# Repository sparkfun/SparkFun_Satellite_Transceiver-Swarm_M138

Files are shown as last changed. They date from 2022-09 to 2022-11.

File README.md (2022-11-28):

SparkFun Satellite Transceiver - Swarm M138
========================================

SparkFun Satellite Transceiver Kit - Swarm M138

[*SparkFun Satellite Transceiver Kit - Swarm M138 (21287)*](https://www.sparkfun.com/products/21287)

Looking for a low-cost way to send and receive data messages via satellite? This is it! With a clear view of the sky, the Satellite Transceiver Kit - Swarm M138 allows you to send and receive short messages. It works anywhere in the world, including the polar regions, far beyond the reach of WiFi and Cellular networks. It is perfect for a variety of low-bandwidth use cases: from connecting people and tracking vehicles, ships, or packages to relaying sensor data for agriculture, energy, and industrial IoT applications. The built-in GNSS receiver makes it perfect for many tracking applications.

At the heart of our product is a Swarm M138 satellite modem. This is a Mini-PCI Express Card containing both the satellite modem and a very capable GNSS receiver, all in one integrated package! It can operate from a wide range of supply voltages: 3.0V Min; 5.0V Max. Its standard 3.3V CMOS serial UART interface and NMEA-style command set makes it easy to integrate into your project. Our board includes both a USB-C interface (for power and/or serial data) and a full set of breakout pins. Want to plug it into your laptop or Raspberry Pi and use it to communicate out in the field? You can absolutely do that! We've written a Python3 PyQt5 GUI to get you started. Full details are available in the [hookup guide](https://learn.sparkfun.com/tutorials/sparkfun-satellite-transceiver-kit---swarm-m138-hookup-guide) and in the [product repo](https://github.com/sparkfun/SparkFun_Satellite_Transceiver-Swarm_M138). Want to connect it to your Arduino microcontroller board? You can absolutely do that too! Our [Swarm Arduino Library](https://github.com/sparkfun/SparkFun_Swarm_Satellite_Arduino_Library) makes that easy.

Our kit contains everything you need to get started:

* Swarm M138 Modem
* SparkFun Satellite Transceiver Breakout
* VHF Antenna and Ground Plane
* GNSS Antenna
* u.FL cables, adapter and screws

Repository Contents
-------------------

* **/Documentation** - Data sheets, additional product information
* **/Hardware** - Eagle design files (.brd, .sch)
* **/Production** - Production panel files (.brd)
* **/Tools/Swarm_M138_GUI** - Executables, Python files

Documentation
--------------
* **[Library](https://github.com/sparkfun/SparkFun_Swarm_Satellite_Arduino_Library)** - Arduino library for the SparkFun Satellite Transceiver Kit - Swarm M138.
* **[Hookup Guide](https://learn.sparkfun.com/tutorials/sparkfun-satellite-transceiver-kit---swarm-m138-hookup-guide)** - Basic hookup guide for the SparkFun Satellite Transceiver Kit - Swarm M138.

Product Versions
----------------
* [SPX-19236](https://www.sparkfun.com/products/19236)- SparkX version of this kit

License Information
-------------------

This product is _**open source**_! 

Please review the LICENSE.md file for license information. 

If you have any questions or concerns on licensing, please contact technical support on our [SparkFun forums](https://forum.sparkfun.com/viewforum.php?f=152).

Distributed as-is; no warranty is given.

- Your friends at SparkFun.

_<COLLABORATION CREDIT>_

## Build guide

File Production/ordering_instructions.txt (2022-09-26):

panel size, 158x103mm
PCB thickness, 1.6mm
number of layers, 2
soldermask color, Red
silkscreen color, White
oz copper, 1oz
finish, HASL lead free
stencils, top
pcs per panel, 4
min trace width, 0.1524mm / 0.0060in
min drill size, 0.3000mm / 0.0118in

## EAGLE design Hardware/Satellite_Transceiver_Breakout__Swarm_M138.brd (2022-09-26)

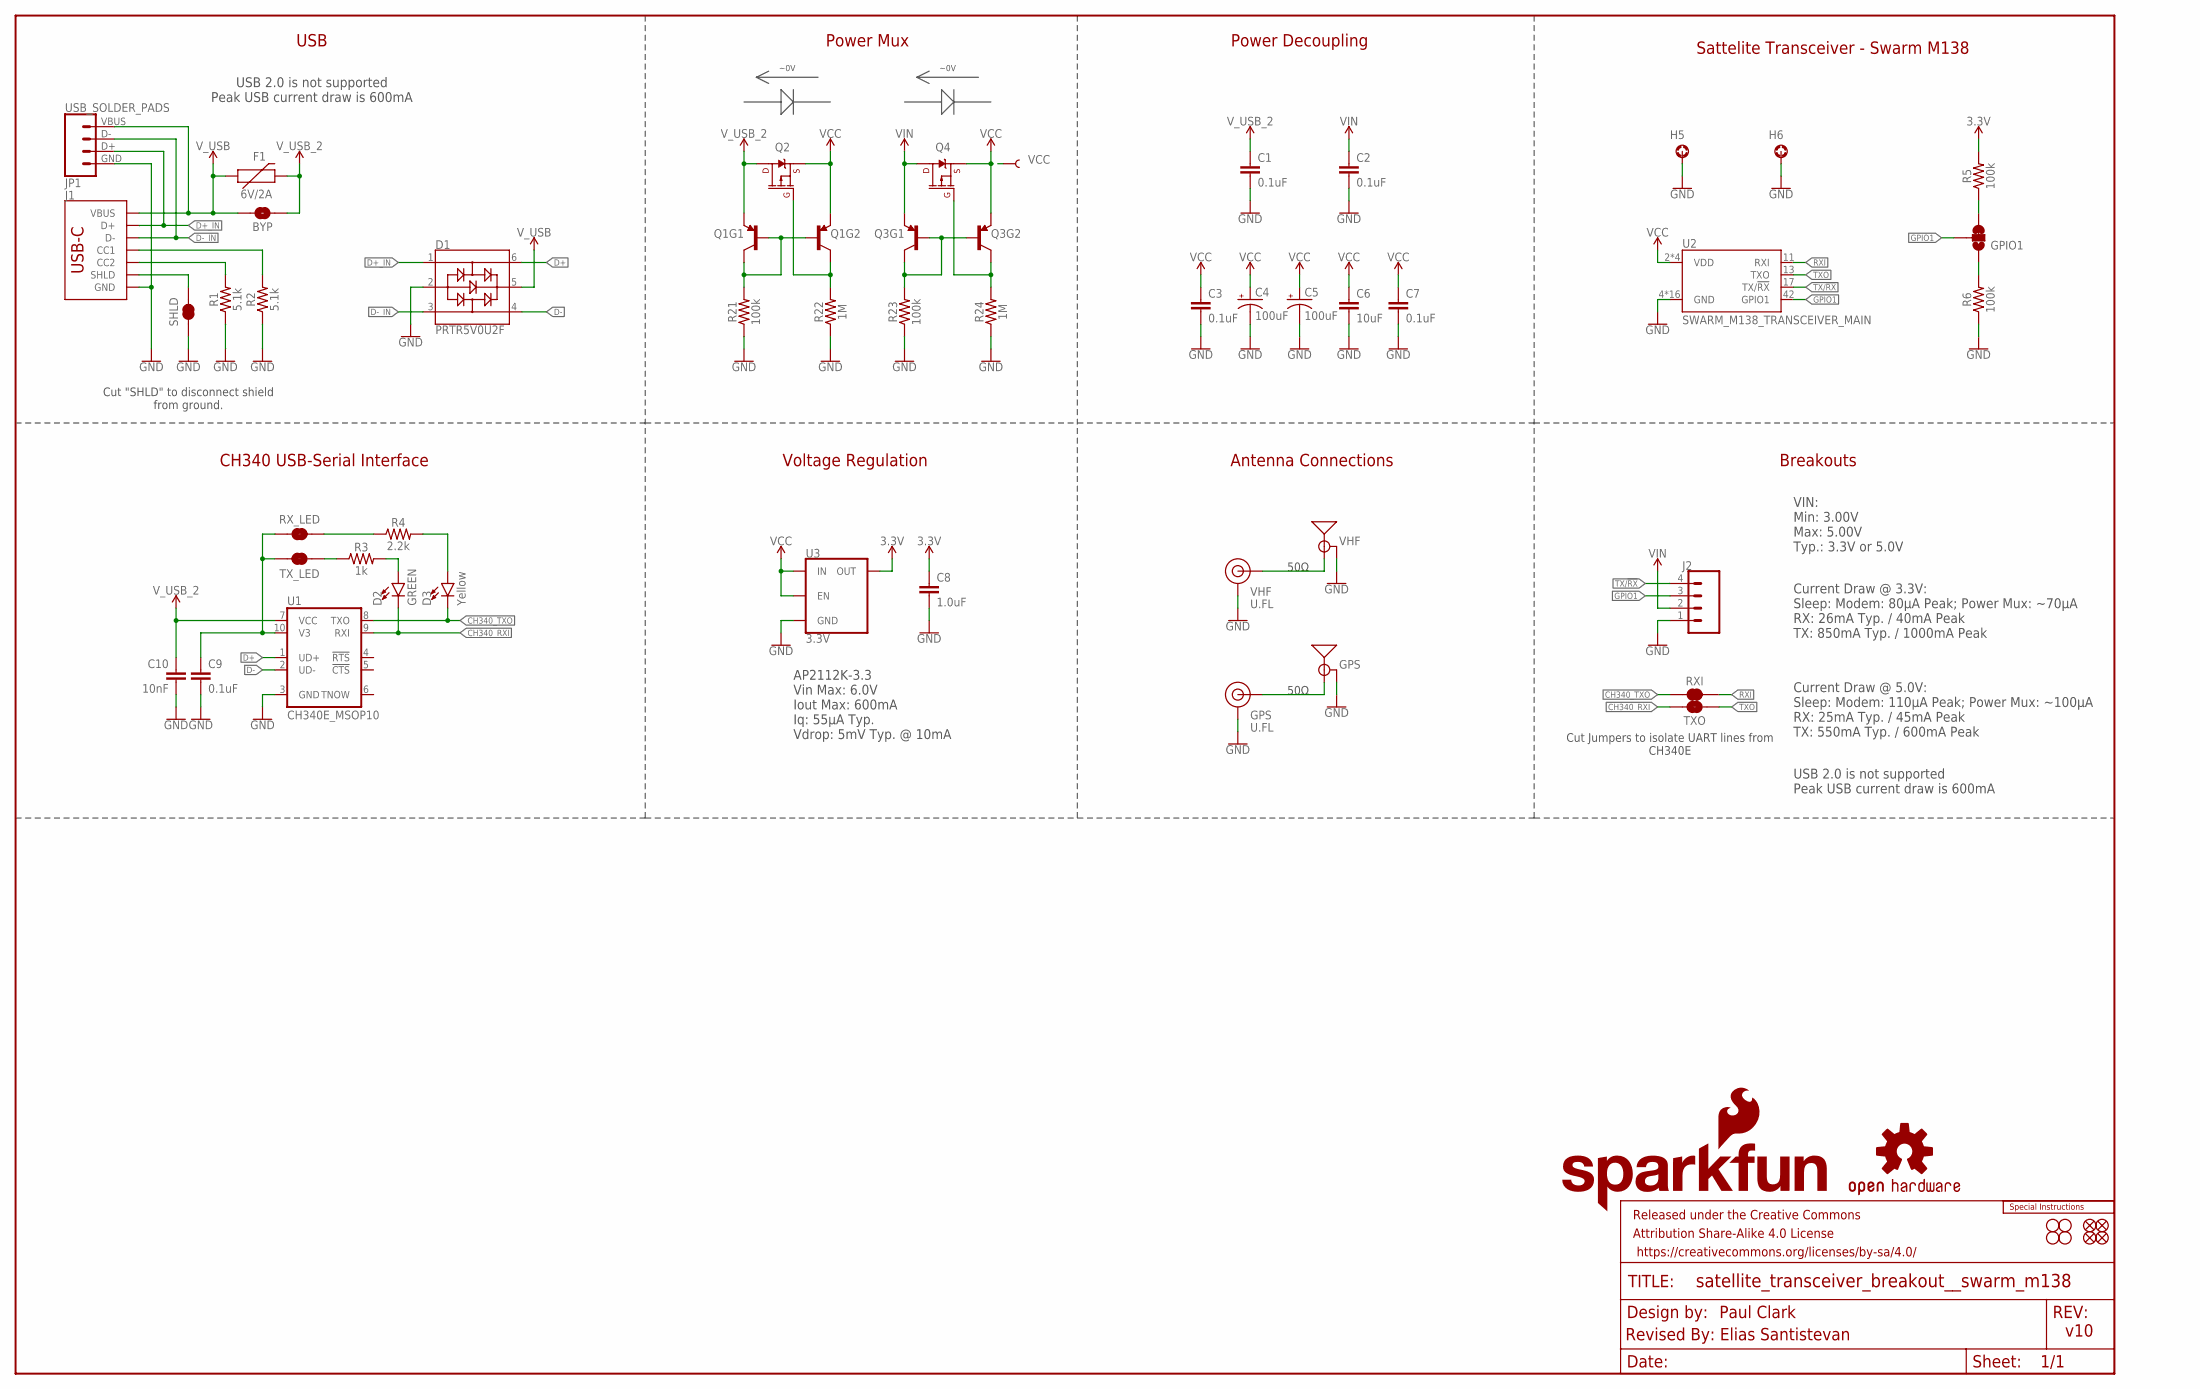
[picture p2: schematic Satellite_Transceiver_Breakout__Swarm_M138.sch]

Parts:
BYP: JUMPER-SMT_2_NO_SILK; SMT-JUMPER_2_NO_SILK
C1, C2, C3, C7, C9: 0.1uF; 0603
C4, C5: 100uF; PANASONIC_D
C6: 10uF; 0603
C8: 1.0uF; 0603
C10: 10nF; 0603
D1: PRTR5V0U2F; SOT886
D2: GREEN; LED-0603
D3: Yellow; LED-0603
E1: VHF; SMA-EDGE
E2: GPS; SMA-EDGE
F1: 6V/2A; 1210
FD1, FD2, FD3, FD4: FIDUCIAL1X2; FIDUCIAL-1X2
FRAME1: FRAME-LEDGER; CREATIVE_COMMONS
GPIO1: JUMPER-SMT_3_1-NC_TRACE_SILK; SMT-JUMPER_3_1-NC_TRACE_SILK
GPS: U.FL
H1, H2, H3, H4: STAND-OFF
H5, H6: STAND-OFF-REFLOW-M2.5_1.5MM_TALL; STAND-OFF-REFLOW-M2.5
J1: USB_C_2-LAYER_PADS; USB-C-16P-2LAYER-PADS
J2: CONN_041X04_NO_SILK; 1X04_NO_SILK
JP1: USB_SOLDER_PADS; USB-SOLDER-PADS
LOGO1: SPECIAL_INSTRUCTIONS-ORDERING; ORDERING_INSTRUCTIONS
LOGO2: OSHW-LOGOM; OSHW-LOGO-M
LOGO4: SFE_LOGO_NAME_FLAME.1_INCH; SFE_LOGO_NAME_FLAME_.1
Q1, Q3: TRANS_PNP_DUALSOT-363; SOT363_PHILIPS
Q2, Q4: 20V/4.2A/52mΩ/1.4W; SOT23-3
R1, R2: 5.1k; 0603
R3: 1k; 0603
R4: 2.2k; 0603
R5, R6, R21, R23: 100k; 0603
R22, R24: 1M; 0603
RXI: JUMPER-COMBO_2_NC_TRACE; COMBO-JUMPER_2_NC_TRACE
RX_LED: JUMPER-SMT_2_NC_TRACE_SILK; SMT-JUMPER_2_NC_TRACE_SILK
SHLD: JUMPER-SMT_2_NC_TRACE_SILK; SMT-JUMPER_2_NC_TRACE_SILK
TXO: JUMPER-COMBO_2_NC_TRACE; COMBO-JUMPER_2_NC_TRACE
TX_LED: JUMPER-SMT_2_NC_TRACE_SILK; SMT-JUMPER_2_NC_TRACE_SILK
U1: CH340E_MSOP10; MSOP10
U2: SWARM_M138_TRANSCEIVER_MAIN; M.2-SWARM-M138-A
U3: 3.3V; SOT23-5
VCC: TEST-POINT3X5; PAD.03X.05
VHF: U.FL

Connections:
3.3V: C8.1, R5.2, U3.5 (OUT)
CH340_RXI: D2.C, TXO.2, TXO.4 (2), U1.9 (RXI)
CH340_TXO: D3.C, RXI.1, RXI.3 (1), U1.8 (TXO)
D+: D1.6, U1.1 (UD+)
D+_IN: D1.1, J1.A6 (D+), J1.B6 (D+), JP1.D+ (3)
D-: D1.4, U1.2 (UD-)
D-_IN: D1.3, J1.A7 (D-), J1.B7 (D-), JP1.D- (2)
GND: C1.2, C2.2, C3.2, C4.-, C5.-, C6.2, C7.2, C8.2, C9.2, C10.2, D1.2, E1.GND@0 (GND), E1.GND@1 (GND), E1.GND@2 (GND), E1.GND@3 (GND), E2.GND@0 (GND), E2.GND@1 (GND), E2.GND@2 (GND), E2.GND@3 (GND), GPS.1 (GND), GPS.2 (GND), H5.1, H6.1, J1.GND, J1.GND2 (GND), J2.1, JP1.GND (4), R1.1, R2.1, R6.1, R21.1, R22.1, R23.1, R24.1, SHLD.1, U1.3 (GND), U2.4 (GND), U2.9 (GND), U2.15 (GND), U2.18 (GND), U2.21 (GND), U2.26 (GND), U2.27 (GND), U2.29 (GND), U2.34 (GND), U2.35 (GND), U2.37 (GND), U2.40 (GND), U2.43 (GND), U2.50 (GND), U2.A1 (GND), U2.A2 (GND), U3.2 (GND), VHF.1 (GND), VHF.2 (GND)
GPIO1: GPIO1.2, J2.3, U2.42 (GPIO1)
GPS: E2.SIG (SIGNAL), GPS.FEED (SIGNAL)
unnamed: J1.B5 (CC2), R1.2
unnamed: J1.A5 (CC1), R2.2
unnamed: Q1.2 (B), Q1.5 (B), Q1.6 (C), R21.2
unnamed: C9.1, RX_LED.1, TX_LED.2, U1.10 (V3)
unnamed: R4.1, RX_LED.2
unnamed: D2.A, R3.2
unnamed: D3.A, R4.2
unnamed: R3.1, TX_LED.1
unnamed: Q1.3 (C), Q2.1 (G), R22.2
unnamed: GPIO1.3, R5.1
unnamed: Q3.2 (B), Q3.5 (B), Q3.6 (C), R23.2
unnamed: GPIO1.1, R6.2
unnamed: Q3.3 (C), Q4.1 (G), R24.2
RXI: RXI.2, RXI.4 (2), U2.11 (RXI)
SHLD: J1.SHLD1 (SHLD), J1.SHLD2 (SHLD), J1.SHLD3 (SHLD), J1.SHLD4 (SHLD), SHLD.2
TX/!RX!: J2.4, U2.17 (TX/!RX!)
TXO: TXO.1, TXO.3 (1), U2.13 (TXO)
VCC: C3.1, C4.+, C5.+, C6.1, C7.1, Q1.4 (E), Q2.2 (S), Q3.4 (E), Q4.2 (S), U2.2 (VDD), U2.39 (VDD), U2.41 (VDD), U2.52 (VDD), U3.1 (IN), U3.3 (EN), VCC.1
VHF: E1.SIG (SIGNAL), VHF.FEED (SIGNAL)
VIN: C2.1, J2.2, Q3.1 (E), Q4.3 (D)
V_USB: BYP.2, D1.5, F1.1, J1.VBUS1 (VBUS), J1.VBUS2 (VBUS), JP1.VBUS (1)
V_USB_2: BYP.1, C1.1, C10.1, F1.2, Q1.1 (E), Q2.3 (D), U1.7 (VCC)

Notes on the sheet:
v10
Paul Clark
USB
Power Mux
~0V
Power Decoupling
CH340 USB-Serial Interface
Sattelite Transceiver - Swarm M138
Antenna Connections
50Ω
Breakouts
VIN: Min: 3.00V Max: 5.00V Typ.: 3.3V or 5.0V
Current Draw @ 3.3V: Sleep: Modem: 80µA Peak; Power Mux: ~70µA RX: 26mA Typ. / 40mA Peak TX: 850mA Typ. / 1000mA Peak
Current Draw @ 5.0V: Sleep: Modem: 110µA Peak; Power Mux: ~100µA RX: 25mA Typ. / 45mA Peak TX: 550mA Typ. / 600mA Peak
USB 2.0 is not supported Peak USB current draw is 600mA
Voltage Regulation
AP2112K-3.3 Vin Max: 6.0V Iout Max: 600mA Iq: 55µA Typ. Vdrop: 5mV Typ. @ 10mA
Revised By: Elias Santistevan
Cut "SHLD" to disconnect shield from ground.
Cut Jumpers to isolate UART lines from CH340E

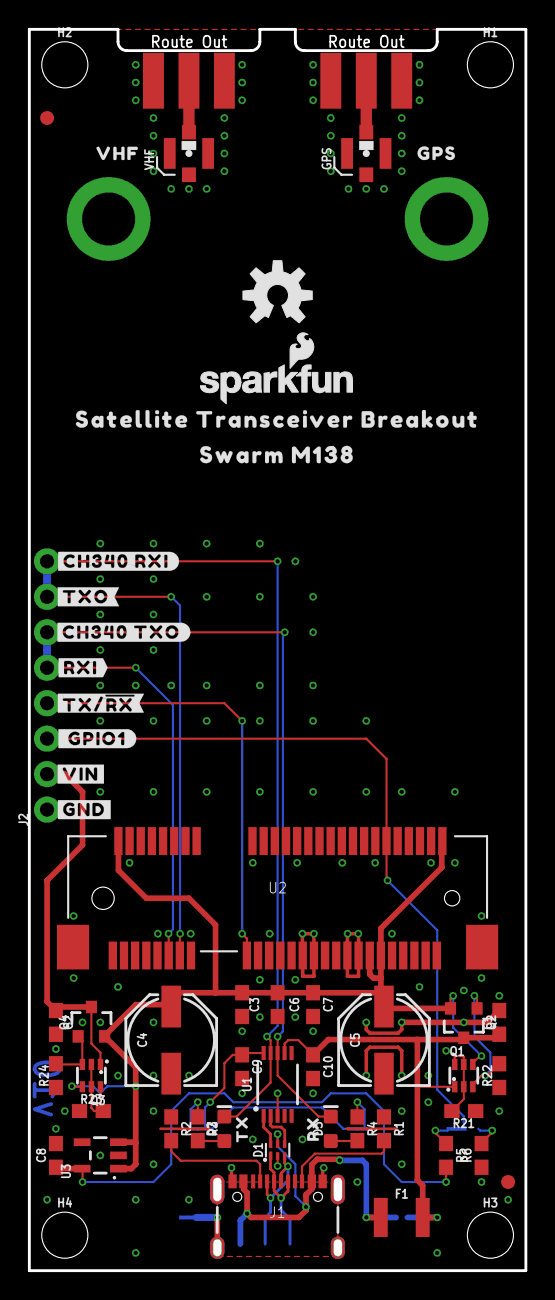
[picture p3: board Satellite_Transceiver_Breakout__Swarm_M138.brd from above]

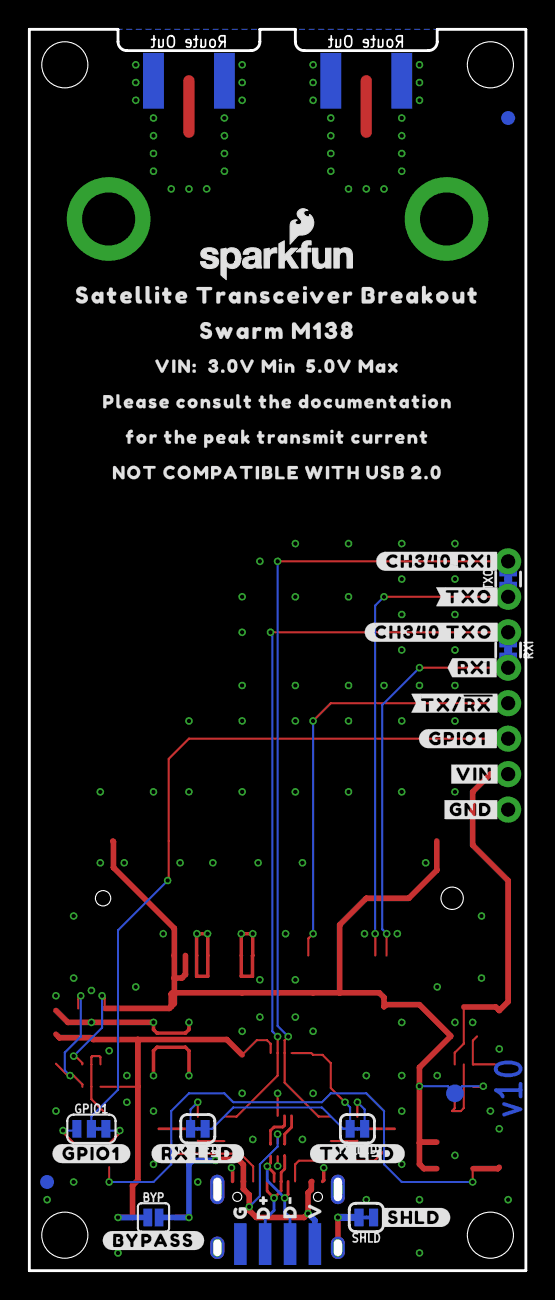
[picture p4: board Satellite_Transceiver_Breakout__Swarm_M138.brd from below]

Board: 2 copper layers, 35.6 x 88.9 mm, 98 parts (35 on the bottom side), 32 nets.

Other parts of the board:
LOGO3: SFE_LOGO_NAME_FLAME.1_INCH; SFE_LOGO_NAME_FLAME_.1
U$1: #SHLD#14
U$3: VHF0
U$4: GPS0
U$5: VIN#__3#0V_MIN__5#0V_MAX0
U$6: PLEASE_CONSULT_THE_DOCUMENTATION0
U$7: #CH340_RXI#0
U$8: #CH340_RXI#341
U$9: #TXO#341
U$10: #TXO#342
U$11: #CH340_TXO#0
U$12: #CH340_TXO#341
U$13: #RXI#0
U$14: #RXI#1
U$15: #TX##RX##1
U$16: #TX##RX##0
U$17: #GPIO1_#2
U$18: V0
U$19: #GPIO1#0
U$20: #_GPIO1#2
U$21, U$22: #VIN#0
U$23, U$24: #GND#0
U$25: TX0
U$26: RX0
U$27: #TX_LED#0
U$28: #RX_LED#0
U$29: #BYPASS#0
U$30: G3
U$31: FOR_THE_PEAK_TRANSMIT_CURRENT1
U$32: NOT_COMPATIBLE_WITH_USB_2#02
U$34, U$39: SATELLITE_TRANSCEIVER_BREAKOUT0
U$36: D#2
U$37: D#1
U$40, U$41: SWARM_M1381

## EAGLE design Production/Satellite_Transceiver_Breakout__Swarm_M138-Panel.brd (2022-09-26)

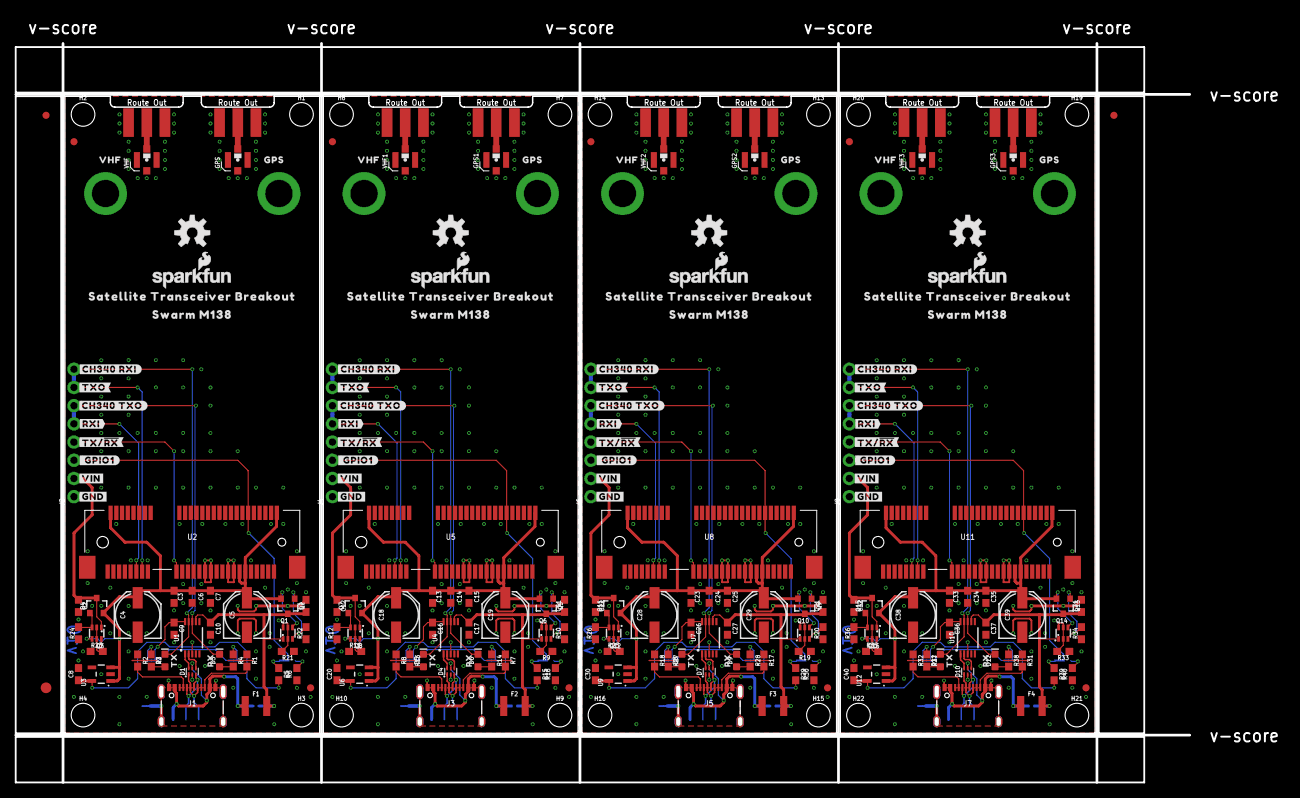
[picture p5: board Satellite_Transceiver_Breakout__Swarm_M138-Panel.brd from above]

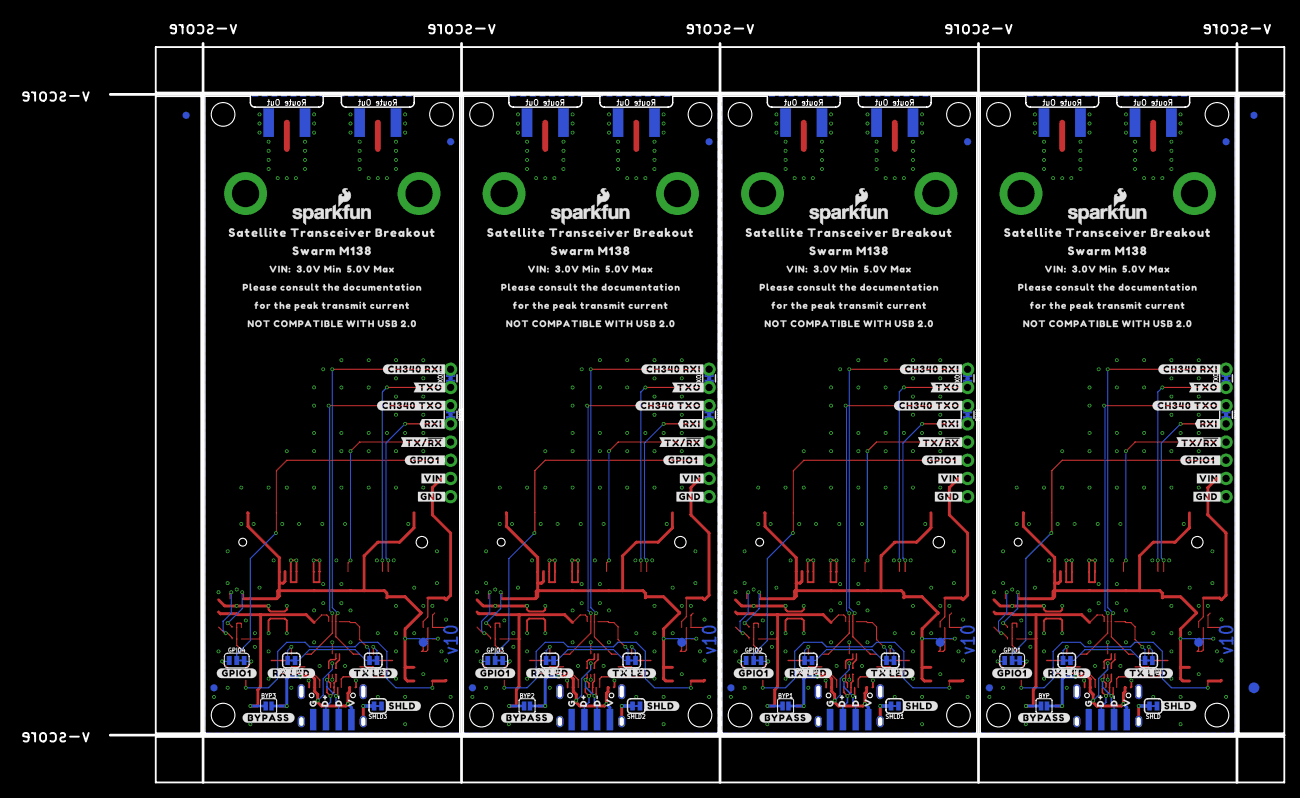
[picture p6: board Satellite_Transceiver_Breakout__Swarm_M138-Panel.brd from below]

Board: 2 copper layers, 163.8 x 103.1 mm, 390 parts (143 on the bottom side), 128 nets.

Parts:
BYP, BYP1, BYP2, BYP3: JUMPER-SMT_2_NO_SILK; SMT-JUMPER_2_NO_SILK
C1, C2, C3, C7, C9, C11, C12, C13, C15, C16, C21, C22, C23, C25, C26, C31, C32, C33, C35, C36: 0.1uF; 0603
C4, C5, C18, C19, C28, C29, C38, C39: 100uF; PANASONIC_D
C6, C14, C24, C34: 10uF; 0603
C8, C20, C30, C40: 1.0uF; 0603
C10, C17, C27, C37: 10nF; 0603
D1, D4, D7, D10: PRTR5V0U2F; SOT886
D2, D5, D8, D11: GREEN; LED-0603
D3, D6, D9, D12: Yellow; LED-0603
E1, E3, E5, E7: VHF; SMA-EDGE
E2, E4, E6, E8: GPS; SMA-EDGE
E$1, E$2, E$3, E$4: FIDUCIAL-1X2
E$5, E$6: FIDUCIAL-1.5X3
F1, F2, F3, F4: 6V/2A; 1210
FD1, FD2, FD3, FD4, FD5, FD6, FD7, FD8, FD9, FD10, FD11, FD12, FD13, FD14, FD15, FD16: FIDUCIAL1X2; FIDUCIAL-1X2
GPIO1, GPIO2, GPIO3, GPIO4: JUMPER-SMT_3_1-NC_TRACE_SILK; SMT-JUMPER_3_1-NC_TRACE_SILK
GPS, GPS1, GPS2, GPS3: U.FL
H1, H2, H3, H4, H7, H8, H9, H10, H13, H14, H15, H16, H19, H20, H21, H22: STAND-OFF
H5, H6, H11, H12, H17, H18, H23, H24: STAND-OFF-REFLOW-M2.5_1.5MM_TALL; STAND-OFF-REFLOW-M2.5
J1, J3, J5, J7: USB-C-16P-2LAYER-PADS
J2, J4, J6, J8: 1X04_NO_SILK
JP1, JP2, JP3, JP4: USB_SOLDER_PADS; USB-SOLDER-PADS
LOGO1, LOGO2, LOGO7, LOGO10: OSHW-LOGOM; OSHW-LOGO-M
LOGO3, LOGO4, LOGO5, LOGO6, LOGO8, LOGO9, LOGO11, LOGO12: SFE_LOGO_NAME_FLAME.1_INCH; SFE_LOGO_NAME_FLAME_.1
Q1, Q3, Q6, Q8, Q10, Q12, Q14, Q16: SOT363_PHILIPS
Q2, Q4, Q5, Q7, Q9, Q11, Q13, Q15: 20V/4.2A/52mΩ/1.4W; SOT23-3
R1, R2, R7, R8, R17, R18, R31, R32: 5.1k; 0603
R3, R13, R27, R37: 1k; 0603
R4, R14, R28, R38: 2.2k; 0603
R5, R6, R9, R11, R15, R16, R19, R21, R23, R25, R29, R30, R33, R35, R39, R40: 100k; 0603
R10, R12, R20, R22, R24, R26, R34, R36: 1M; 0603
RXI, RXI1, RXI2, RXI3: JUMPER-COMBO_2_NC_TRACE; COMBO-JUMPER_2_NC_TRACE
RX_LED, RX_LED1, RX_LED2, RX_LED3: JUMPER-SMT_2_NC_TRACE_SILK; SMT-JUMPER_2_NC_TRACE_SILK
SHLD, SHLD1, SHLD2, SHLD3: JUMPER-SMT_2_NC_TRACE_SILK; SMT-JUMPER_2_NC_TRACE_SILK
TXO, TXO1, TXO2, TXO3: JUMPER-COMBO_2_NC_TRACE; COMBO-JUMPER_2_NC_TRACE
TX_LED, TX_LED1, TX_LED2, TX_LED3: JUMPER-SMT_2_NC_TRACE_SILK; SMT-JUMPER_2_NC_TRACE_SILK
U1, U4, U7, U10: CH340E_MSOP10; MSOP10
U2, U5, U8, U11: SWARM_M138_TRANSCEIVER_MAIN; M.2-SWARM-M138-A
U3, U6, U9, U12: 3.3V; SOT23-5
U$1, U$74, U$111, U$148: #SHLD#14
U$2, U$3, U$75, U$112: VHF0
U$4, U$33, U$76, U$113: GPS0
U$5, U$73, U$110, U$147: VIN#__3#0V_MIN__5#0V_MAX0
U$6, U$70, U$107, U$144: PLEASE_CONSULT_THE_DOCUMENTATION0
U$7, U$49, U$86, U$123: #CH340_RXI#0
U$8, U$50, U$87, U$124: #CH340_RXI#341
U$9, U$51, U$88, U$125: #TXO#341
U$10, U$52, U$89, U$126: #TXO#342
U$11, U$53, U$90, U$127: #CH340_TXO#0
U$12, U$54, U$91, U$128: #CH340_TXO#341
U$13, U$55, U$92, U$129: #RXI#0
U$14, U$56, U$93, U$130: #RXI#1
U$15, U$58, U$95, U$132: #TX##RX##1
U$16, U$57, U$94, U$131: #TX##RX##0
U$17, U$60, U$97, U$134: #GPIO1_#2
U$18, U$62, U$99, U$136: V0
U$19, U$59, U$96, U$133: #GPIO1#0
U$20, U$61, U$98, U$135: #_GPIO1#2
U$21, U$22, U$35, U$38, U$77, U$78, U$114, U$115: #VIN#0
U$23, U$24, U$42, U$43, U$79, U$80, U$116, U$117: #GND#0
U$25, U$44, U$81, U$118: TX0
U$26, U$45, U$82, U$119: RX0
U$27, U$46, U$83, U$120: #TX_LED#0
U$28, U$47, U$84, U$121: #RX_LED#0
U$29, U$48, U$85, U$122: #BYPASS#0
U$30, U$63, U$100, U$137: G3
U$31, U$71, U$108, U$145: FOR_THE_PEAK_TRANSMIT_CURRENT1
U$32, U$72, U$109, U$146: NOT_COMPATIBLE_WITH_USB_2#02
U$34, U$39, U$66, U$67, U$103, U$104, U$140, U$141: SATELLITE_TRANSCEIVER_BREAKOUT0
U$36, U$64, U$101, U$138: D#2
U$37, U$65, U$102, U$139: D#1
U$40, U$41, U$68, U$69, U$105, U$106, U$142, U$143: SWARM_M1381
VCC, VCC1, VCC2, VCC3: TEST-POINT3X5; PAD.03X.05
VHF, VHF1, VHF2, VHF3: U.FL

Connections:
3.3V: C8.1, R5.2, U3.5
3.3V1: C20.1, R15.2, U6.5
3.3V2: C30.1, R29.2, U9.5
3.3V3: C40.1, R39.2, U12.5
CH340_RXI: D2.C, TXO.2, TXO.4, U1.9
CH340_RXI1: D5.C, TXO1.2, TXO1.4, U4.9
CH340_RXI2: D8.C, TXO2.2, TXO2.4, U7.9
CH340_RXI3: D11.C, TXO3.2, TXO3.4, U10.9
CH340_TXO: D3.C, RXI.1, RXI.3, U1.8
CH340_TXO1: D6.C, RXI1.1, RXI1.3, U4.8
CH340_TXO2: D9.C, RXI2.1, RXI2.3, U7.8
CH340_TXO3: D12.C, RXI3.1, RXI3.3, U10.8
D+: D1.6, U1.1
D+1: D4.6, U4.1
D+2: D7.6, U7.1
D+3: D10.6, U10.1
D+_IN: D1.1, J1.A6, J1.B6, JP1.D+
D+_IN1: D4.1, J3.A6, J3.B6, JP2.D+
D+_IN2: D7.1, J5.A6, J5.B6, JP3.D+
D+_IN3: D10.1, J7.A6, J7.B6, JP4.D+
D-: D1.4, U1.2
D-1: D4.4, U4.2
D-2: D7.4, U7.2
D-3: D10.4, U10.2
D-_IN: D1.3, J1.A7, J1.B7, JP1.D-
D-_IN1: D4.3, J3.A7, J3.B7, JP2.D-
D-_IN2: D7.3, J5.A7, J5.B7, JP3.D-
D-_IN3: D10.3, J7.A7, J7.B7, JP4.D-
GND: C1.2, C2.2, C3.2, C4.-, C5.-, C6.2, C7.2, C8.2, C9.2, C10.2, D1.2, E1.GND@0, E1.GND@1, E1.GND@2, E1.GND@3, E2.GND@0, E2.GND@1, E2.GND@2, E2.GND@3, GPS.1, GPS.2, H5.1, H6.1, J1.GND, J1.GND2, J2.1, JP1.GND, R1.1, R2.1, R6.1, R21.1, R22.1, R23.1, R24.1, SHLD.1, U1.3, U2.4, U2.9, U2.15, U2.18, U2.21, U2.26, U2.27, U2.29, U2.34, U2.35, U2.37, U2.40, U2.43, U2.50, U2.A1, U2.A2, U3.2, VHF.1, VHF.2
GND1: C11.2, C12.2, C13.2, C14.2, C15.2, C16.2, C17.2, C18.-, C19.-, C20.2, D4.2, E3.GND@0, E3.GND@1, E3.GND@2, E3.GND@3, E4.GND@0, E4.GND@1, E4.GND@2, E4.GND@3, GPS1.1, GPS1.2, H11.1, H12.1, J3.GND, J3.GND2, J4.1, JP2.GND, R7.1, R8.1, R9.1, R10.1, R11.1, R12.1, R16.1, SHLD1.1, U4.3, U5.4, U5.9, U5.15, U5.18, U5.21, U5.26, U5.27, U5.29, U5.34, U5.35, U5.37, U5.40, U5.43, U5.50, U5.A1, U5.A2, U6.2, VHF1.1, VHF1.2
GND2: C21.2, C22.2, C23.2, C24.2, C25.2, C26.2, C27.2, C28.-, C29.-, C30.2, D7.2, E5.GND@0, E5.GND@1, E5.GND@2, E5.GND@3, E6.GND@0, E6.GND@1, E6.GND@2, E6.GND@3, GPS2.1, GPS2.2, H17.1, H18.1, J5.GND, J5.GND2, J6.1, JP3.GND, R17.1, R18.1, R19.1, R20.1, R25.1, R26.1, R30.1, SHLD2.1, U7.3, U8.4, U8.9, U8.15, U8.18, U8.21, U8.26, U8.27, U8.29, U8.34, U8.35, U8.37, U8.40, U8.43, U8.50, U8.A1, U8.A2, U9.2, VHF2.1, VHF2.2
GND3: C31.2, C32.2, C33.2, C34.2, C35.2, C36.2, C37.2, C38.-, C39.-, C40.2, D10.2, E7.GND@0, E7.GND@1, E7.GND@2, E7.GND@3, E8.GND@0, E8.GND@1, E8.GND@2, E8.GND@3, GPS3.1, GPS3.2, H23.1, H24.1, J7.GND, J7.GND2, J8.1, JP4.GND, R31.1, R32.1, R33.1, R34.1, R35.1, R36.1, R40.1, SHLD3.1, U10.3, U11.4, U11.9, U11.15, U11.18, U11.21, U11.26, U11.27, U11.29, U11.34, U11.35, U11.37, U11.40, U11.43, U11.50, U11.A1, U11.A2, U12.2, VHF3.1, VHF3.2
GPIO1: GPIO1.2, J2.3, U2.42
GPIO2: GPIO2.2, J4.3, U5.42
GPIO3: GPIO3.2, J6.3, U8.42
GPIO4: GPIO4.2, J8.3, U11.42
GPS: E2.SIG, GPS.FEED
GPS1: E4.SIG, GPS1.FEED
GPS2: E6.SIG, GPS2.FEED
GPS3: E8.SIG, GPS3.FEED
unnamed: J3.B5, R7.2
unnamed: J1.B5, R1.2
unnamed: J1.A5, R2.2
unnamed: J3.A5, R8.2
unnamed: Q1.2, Q1.5, Q1.6, R21.2
unnamed: C9.1, RX_LED.1, TX_LED.2, U1.10
unnamed: R4.1, RX_LED.2
unnamed: Q6.2, Q6.5, Q6.6, R9.2
unnamed: D2.A, R3.2
unnamed: D3.A, R4.2
unnamed: Q5.1, Q6.3, R10.2
unnamed: R3.1, TX_LED.1
unnamed: Q1.3, Q2.1, R22.2
unnamed: GPIO1.3, R5.1
unnamed: Q3.2, Q3.5, Q3.6, R23.2
unnamed: GPIO1.1, R6.2
unnamed: Q8.2, Q8.5, Q8.6, R11.2
unnamed: Q7.1, Q8.3, R12.2
unnamed: C16.1, RX_LED1.1, TX_LED1.2, U4.10
unnamed: D5.A, R13.2
unnamed: D6.A, R14.2
unnamed: R14.1, RX_LED1.2
unnamed: R13.1, TX_LED1.1
unnamed: GPIO2.3, R15.1
unnamed: GPIO2.1, R16.2
unnamed: J5.B5, R17.2
unnamed: J5.A5, R18.2
unnamed: Q3.3, Q4.1, R24.2
unnamed: Q10.2, Q10.5, Q10.6, R19.2
unnamed: Q9.1, Q10.3, R20.2
unnamed: Q12.2, Q12.5, Q12.6, R25.2
unnamed: Q11.1, Q12.3, R26.2
unnamed: C26.1, RX_LED2.1, TX_LED2.2, U7.10
unnamed: D8.A, R27.2
unnamed: D9.A, R28.2
unnamed: R28.1, RX_LED2.2
unnamed: R27.1, TX_LED2.1
unnamed: GPIO3.3, R29.1
unnamed: GPIO3.1, R30.2
unnamed: J7.B5, R31.2
unnamed: J7.A5, R32.2
unnamed: Q14.2, Q14.5, Q14.6, R33.2
unnamed: Q13.1, Q14.3, R34.2
unnamed: Q16.2, Q16.5, Q16.6, R35.2
unnamed: Q15.1, Q16.3, R36.2
unnamed: C36.1, RX_LED3.1, TX_LED3.2, U10.10
unnamed: D11.A, R37.2
unnamed: D12.A, R38.2
unnamed: R38.1, RX_LED3.2
unnamed: R37.1, TX_LED3.1
unnamed: GPIO4.3, R39.1
unnamed: GPIO4.1, R40.2
RXI: RXI.2, RXI.4, U2.11
RXI1: RXI1.2, RXI1.4, U5.11
RXI2: RXI2.2, RXI2.4, U8.11
RXI3: RXI3.2, RXI3.4, U11.11
SHLD: J1.SHLD1, J1.SHLD2, J1.SHLD3, J1.SHLD4, SHLD.2
SHLD1: J3.SHLD1, J3.SHLD2, J3.SHLD3, J3.SHLD4, SHLD1.2
SHLD2: J5.SHLD1, J5.SHLD2, J5.SHLD3, J5.SHLD4, SHLD2.2
SHLD3: J7.SHLD1, J7.SHLD2, J7.SHLD3, J7.SHLD4, SHLD3.2
TX/!RX!: J2.4, U2.17
TX/!RX!1: J4.4, U5.17
TX/!RX!2: J6.4, U8.17
TX/!RX!3: J8.4, U11.17
TXO: TXO.1, TXO.3, U2.13
TXO1: TXO1.1, TXO1.3, U5.13
TXO2: TXO2.1, TXO2.3, U8.13
TXO3: TXO3.1, TXO3.3, U11.13
VCC: C3.1, C4.+, C5.+, C6.1, C7.1, Q1.4, Q2.2, Q3.4, Q4.2, U2.2, U2.39, U2.41, U2.52, U3.1, U3.3, VCC.1
VCC1: C13.1, C14.1, C15.1, C18.+, C19.+, Q5.2, Q6.4, Q7.2, Q8.4, U5.2, U5.39, U5.41, U5.52, U6.1, U6.3, VCC1.1
VCC2: C23.1, C24.1, C25.1, C28.+, C29.+, Q9.2, Q10.4, Q11.2, Q12.4, U8.2, U8.39, U8.41, U8.52, U9.1, U9.3, VCC2.1
VCC3: C33.1, C34.1, C35.1, C38.+, C39.+, Q13.2, Q14.4, Q15.2, Q16.4, U11.2, U11.39, U11.41, U11.52, U12.1, U12.3, VCC3.1
VHF: E1.SIG, VHF.FEED
VHF1: E3.SIG, VHF1.FEED
VHF2: E5.SIG, VHF2.FEED
VHF3: E7.SIG, VHF3.FEED
VIN: C2.1, J2.2, Q3.1, Q4.3
VIN1: C12.1, J4.2, Q7.3, Q8.1
VIN2: C22.1, J6.2, Q11.3, Q12.1
VIN3: C32.1, J8.2, Q15.3, Q16.1
V_USB: BYP.2, D1.5, F1.1, J1.VBUS1, J1.VBUS2, JP1.VBUS
V_USB1: BYP1.2, D4.5, F2.1, J3.VBUS1, J3.VBUS2, JP2.VBUS
V_USB2: BYP2.2, D7.5, F3.1, J5.VBUS1, J5.VBUS2, JP3.VBUS
V_USB3: BYP3.2, D10.5, F4.1, J7.VBUS1, J7.VBUS2, JP4.VBUS
V_USB_1: BYP1.1, C11.1, C17.1, F2.2, Q5.3, Q6.1, U4.7
V_USB_2: BYP.1, C1.1, C10.1, F1.2, Q1.1, Q2.3, U1.7
V_USB_3: BYP2.1, C21.1, C27.1, F3.2, Q9.3, Q10.1, U7.7
V_USB_4: BYP3.1, C31.1, C37.1, F4.2, Q13.3, Q14.1, U10.7

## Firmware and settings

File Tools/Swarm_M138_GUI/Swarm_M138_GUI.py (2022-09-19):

"""
A simple Python3 PyQt5 GUI for the Swarm M138 Modem

Written by: Paul Clark, SparkFun
Date: April 21st, 2022


Please make sure you are using Python3. You will see a bunch of errors with Python2.

To install PyQt5:

  pip install PyQt5

or

  pip3 install PyQt5

or

  sudo apt-get install python3-pyqt5

You may also need:

  sudo apt-get install python3-pyqt5.qtserialport


MIT license

Please see the LICENSE.md for more details

"""

from typing import Iterator, Tuple

from PyQt5.QtCore import QSettings, QProcess, QTimer, Qt, QIODevice, pyqtSlot
from PyQt5.QtWidgets import QWidget, QLabel, QComboBox, QGridLayout, QPushButton, \
    QApplication, QLineEdit, QFileDialog, QPlainTextEdit
from PyQt5.QtGui import QCloseEvent, QTextCursor
from PyQt5.QtSerialPort import QSerialPort, QSerialPortInfo

# Setting constants
SETTING_PORT_NAME = 'COM1'
SETTING_FILE_LOCATION = 'C:'

guiVersion = 'v1.0'

def gen_serial_ports() -> Iterator[Tuple[str, str, str]]:
    """Return all available serial ports."""
    ports = QSerialPortInfo.availablePorts()
    return ((p.description(), p.portName(), p.systemLocation()) for p in ports)

# noinspection PyArgumentList

class MainWidget(QWidget):
    """Main Widget."""

    def __init__(self, parent: QWidget = None) -> None:
        super().__init__(parent)
 
        self.fileOpen = False

        self.timer=QTimer()
        self.timer.timeout.connect(self.check_port_still_available)

        # File location line edit
        self.msg_label = QLabel(self.tr('Log File:'))
        self.fileLocation_lineedit = QLineEdit()
        self.msg_label.setBuddy(self.msg_label)
        #self.fileLocation_lineedit.setEnabled(False)
        self.fileLocation_lineedit.returnPressed.connect(
            self.on_browse_btn_pressed)

        # Browse for new file button
        self.browse_btn = QPushButton(self.tr('Browse'))
        self.browse_btn.setEnabled(True)
        self.browse_btn.clicked.connect(self.on_browse_btn_pressed)

        # Start Logging Button
        self.start_logging_btn = QPushButton(self.tr('Start Logging'))
        self.start_logging_btn.clicked.connect(self.on_start_logging_btn_pressed)

        # Stop Logging Button
        self.stop_logging_btn = QPushButton(self.tr('Stop Logging'))
        self.stop_logging_btn.clicked.connect(self.on_stop_logging_btn_pressed)

        # Port Combobox
        self.port_label = QLabel(self.tr('COM Port:'))
        self.port_combobox = QComboBox()
        self.port_label.setBuddy(self.port_combobox)
        self.update_com_ports()

        # Refresh Button
        self.refresh_btn = QPushButton(self.tr('Refresh'))
        self.refresh_btn.clicked.connect(self.on_refresh_btn_pressed)

        # Open Port Button
        self.open_port_btn = QPushButton(self.tr('Open Port'))
        self.open_port_btn.clicked.connect(self.on_open_port_btn_pressed)

        # Close Port Button
        self.close_port_btn = QPushButton(self.tr('Close Port'))
        self.close_port_btn.clicked.connect(self.on_close_port_btn_pressed)

        # Send Message Button
        self.send_message_btn = QPushButton(self.tr('Send Message'))
        self.send_message_btn.clicked.connect(self.on_send_message_btn_pressed)

        # Clear Terminal Button
        self.clear_terminal_btn = QPushButton(self.tr('Clear'))
        self.clear_terminal_btn.clicked.connect(self.on_clear_terminal_btn_pressed)

        # Clear Messages Button
        self.clear_message_btn = QPushButton(self.tr('Clear'))
        self.clear_message_btn.clicked.connect(self.on_clear_message_btn_pressed)

        # Terminal Bar
        self.terminal_label = QLabel(self.tr('Serial Monitor:'))

        # Terminal Window
        self.terminal = QPlainTextEdit()

        # Messages Bar
        self.messages_label = QLabel(self.tr('Information / Warnings / Errors:'))

        # Messages Window
        self.messages = QPlainTextEdit()

        # Config Bar
        self.config_label = QLabel(self.tr('Message:'))
        self.config_label_2 = QLabel(self.tr('(The $, * and checksum are added automatically)'))

        # Config Window
        self.config = QPlainTextEdit()

        # Message Labels
        Messages_header = QLabel(self.tr('Pre-defined Messages:'))
        Messages_header.setAlignment(Qt.AlignHCenter | Qt.AlignVCenter)

        self.cs_btn = QPushButton(self.tr('Configuration Settings (CS)'))
        self.cs_btn.clicked.connect(lambda: self.on_message_btn_pressed('CS'))
        self.dt_btn = QPushButton(self.tr('Date/Time Status (DT @)'))
        self.dt_btn.clicked.connect(lambda: self.on_message_btn_pressed('DT @'))
        self.fv_btn = QPushButton(self.tr('Firmware Version (FV)'))
        self.fv_btn.clicked.connect(lambda: self.on_message_btn_pressed('FV'))
        self.gj_btn = QPushButton(self.tr('GPS Jamming (GJ @)'))
        self.gj_btn.clicked.connect(lambda: self.on_message_btn_pressed('GJ @'))
        self.gn_btn = QPushButton(self.tr('Geospatial Info (GN @)'))
        self.gn_btn.clicked.connect(lambda: self.on_message_btn_pressed('GN @'))
        self.gs_btn = QPushButton(self.tr('GPS Fix Quality (GS @)'))
        self.gs_btn.clicked.connect(lambda: self.on_message_btn_pressed('GS @'))
        self.gp_read_btn = QPushButton(self.tr('GPIO1 Read Pin (GP @)'))
        self.gp_read_btn.clicked.connect(lambda: self.on_message_btn_pressed('GP @'))
        self.gp_mode_btn = QPushButton(self.tr('GPIO1 Get Mode (GP ?)'))
        self.gp_mode_btn.clicked.connect(lambda: self.on_message_btn_pressed('GP ?'))
        self.gp_mode1_btn = QPushButton(self.tr('GPIO1 Set Mode - Analog (GP 1)'))
        self.gp_mode1_btn.clicked.connect(lambda: self.on_message_btn_pressed('GP 1'))
        self.gp_mode2_btn = QPushButton(self.tr('GPIO1 Set Mode - Input (GP 2)'))
        self.gp_mode2_btn.clicked.connect(lambda: self.on_message_btn_pressed('GP 2'))
        self.gp_mode5_btn = QPushButton(self.tr('GPIO1 Set Mode - Output Low (GP 5)'))
        self.gp_mode5_btn.clicked.connect(lambda: self.on_message_btn_pressed('GP 5'))
        self.gp_mode6_btn = QPushButton(self.tr('GPIO1 Set Mode - Output High (GP 6)'))
        self.gp_mode6_btn.clicked.connect(lambda: self.on_message_btn_pressed('GP 6'))
        self.mm_count_btn = QPushButton(self.tr('Messages Received - Count Unread (MM C=U)'))
        self.mm_count_btn.clicked.connect(lambda: self.on_message_btn_pressed('MM C=U'))
        self.mm_old_btn = QPushButton(self.tr('Messages Received - Read Oldest (MM R=O)'))
        self.mm_old_btn.clicked.connect(lambda: self.on_message_btn_pressed('MM R=O'))
        self.mm_new_btn = QPushButton(self.tr('Messages Received - Read Newest (MM R=N)'))
        self.mm_new_btn.clicked.connect(lambda: self.on_message_btn_pressed('MM R=N'))
        self.mm_notify_on_btn = QPushButton(self.tr('Messages Received - Notify Enable (MM N=E)'))
        self.mm_notify_on_btn.clicked.connect(lambda: self.on_message_btn_pressed('MM N=E'))
        self.mm_notify_off_btn = QPushButton(self.tr('Messages Received - Notify Disable (MM N=D)'))
        self.mm_notify_off_btn.clicked.connect(lambda: self.on_message_btn_pressed('MM N=D'))
        self.mt_count_btn = QPushButton(self.tr('Message Transmit - Count Unsent (MT C=U)'))
        self.mt_count_btn.clicked.connect(lambda: self.on_message_btn_pressed('MT C=U'))
        self.mt_delete_btn = QPushButton(self.tr('Message Transmit - Delete All Unsent (MT D=U)'))
        self.mt_delete_btn.clicked.connect(lambda: self.on_message_btn_pressed('MT D=U'))
        self.po_btn = QPushButton(self.tr('Power Off (PO)'))
        self.po_btn.clicked.connect(lambda: self.on_message_btn_pressed('PO'))
        self.pw_btn = QPushButton(self.tr('Power Status (PW @)'))
        self.pw_btn.clicked.connect(lambda: self.on_message_btn_pressed('PW @'))
        self.rs_btn = QPushButton(self.tr('Restart Device (RS)'))
        self.rs_btn.clicked.connect(lambda: self.on_message_btn_pressed('RS'))
        self.rt_on_btn = QPushButton(self.tr('Receive Test 1Hz (RT 1)'))
        self.rt_on_btn.clicked.connect(lambda: self.on_message_btn_pressed('RT 1'))
        self.rt_off_btn = QPushButton(self.tr('Receive Test Stop (RT 0)'))
        self.rt_off_btn.clicked.connect(lambda: self.on_message_btn_pressed('RT 0'))
        self.td_btn = QPushButton(self.tr('Transmit Text - Hello World! (TD)'))
        self.td_btn.clicked.connect(lambda: self.on_message_btn_pressed('TD \"Hello World!\"'))
        self.td_bin_btn = QPushButton(self.tr('Transmit Binary - 00 01 02 03 04 05 (TD)'))
        self.td_bin_btn.clicked.connect(lambda: self.on_message_btn_pressed('TD 000102030405'))

        # Arrange Layout
        
        layout = QGridLayout()
        
        layout.addWidget(self.msg_label, 0, 0)
        layout.addWidget(self.fileLocation_lineedit, 0, 1)
        layout.addWidget(self.browse_btn, 0, 2)
        layout.addWidget(self.start_logging_btn, 1, 2)
        layout.addWidget(self.stop_logging_btn, 2, 2)
        layout.addWidget(self.port_label, 4, 0)
        layout.addWidget(self.port_combobox, 4, 1)
        layout.addWidget(self.refresh_btn, 4, 2)
        layout.addWidget(self.open_port_btn, 5, 2)
        layout.addWidget(self.close_port_btn, 6, 2)
        layout.addWidget(self.terminal_label, 8, 0)
        layout.addWidget(self.clear_terminal_btn, 8, 2)
        layout.addWidget(self.terminal, 9, 0, 10, 3)
        layout.addWidget(self.messages_label, 19, 0)
        layout.addWidget(self.clear_message_btn, 19, 2)
        layout.addWidget(self.messages, 20, 0, 3, 3)
        layout.addWidget(self.config_label, 23, 0)
        layout.addWidget(self.config_label_2, 23, 1)
        layout.addWidget(self.send_message_btn, 23, 2)
        layout.addWidget(self.config, 24, 0, 3, 3)

        layout.addWidget(Messages_header, 0, 4)

        layout.addWidget(self.cs_btn, 1, 4)
        layout.addWidget(self.dt_btn, 2, 4)
        layout.addWidget(self.fv_btn, 3, 4)
        layout.addWidget(self.gj_btn, 4, 4)
        layout.addWidget(self.gn_btn, 5, 4)
        layout.addWidget(self.gs_btn, 6, 4)
        layout.addWidget(self.gp_read_btn, 7, 4)
        layout.addWidget(self.gp_mode_btn, 8, 4)
        layout.addWidget(self.gp_mode1_btn, 9, 4)
        layout.addWidget(self.gp_mode2_btn, 10, 4)
        layout.addWidget(self.gp_mode5_btn, 11, 4)
        layout.addWidget(self.gp_mode6_btn, 12, 4)
        layout.addWidget(self.mm_count_btn, 13, 4)
        layout.addWidget(self.mm_old_btn, 14, 4)
        layout.addWidget(self.mm_new_btn, 15, 4)
        layout.addWidget(self.mm_notify_on_btn, 16, 4)
        layout.addWidget(self.mm_notify_off_btn, 17, 4)
        layout.addWidget(self.mt_count_btn, 18, 4)
        layout.addWidget(self.mt_delete_btn, 19, 4)
        layout.addWidget(self.po_btn, 20, 4)
        layout.addWidget(self.pw_btn, 21, 4)
        layout.addWidget(self.rs_btn, 22, 4)
        layout.addWidget(self.rt_on_btn, 23, 4)
        layout.addWidget(self.rt_off_btn, 24, 4)
        layout.addWidget(self.td_btn, 25, 4)
        layout.addWidget(self.td_bin_btn, 26, 4)

        self.setLayout(layout)

        self.load_settings()

        # Make these text edit windows read-only
        self.terminal.setReadOnly(True)
        self.messages.setReadOnly(True)

    def load_settings(self) -> None:
        """Load Qsettings on startup."""
        self.settings = QSettings()
        
        port_name = self.settings.value(SETTING_PORT_NAME)
        if port_name is not None:
            index = self.port_combobox.findData(port_name)
            if index > -1:
                self.port_combobox.setCurrentIndex(index)

        msg = self.settings.value(SETTING_FILE_LOCATION)
        if msg is not None:
            self.fileLocation_lineedit.setText(msg)

    def save_settings(self) -> None:
        """Save Qsettings on shutdown."""
        self.settings = QSettings()
        self.settings.setValue(SETTING_PORT_NAME, self.port)
        self.settings.setValue(SETTING_FILE_LOCATION,
                          self.fileLocation_lineedit.text())

    def on_browse_btn_pressed(self) -> None:
        """Open dialog to select bin file."""
        options = QFileDialog.Options()
        fileName, _ = QFileDialog.getOpenFileName(
            None,
            "Select Configuration File",
            "",
            "Log Files (*.txt);;All Files (*)",
            options=options)
        if fileName:
            self.fileLocation_lineedit.setText(fileName)
     
    def on_refresh_btn_pressed(self) -> None:
        """Refresh the list of serial (COM) ports"""
        self.update_com_ports()

    def on_message_btn_pressed(self, message) -> None:
        """Paste the appropriate message and send it"""

        self.config.clear() # Clear the config window
        self.config.moveCursor(QTextCursor.End)
        self.config.ensureCursorVisible()
        self.config.appendPlainText(message)
        self.config.ensureCursorVisible()
        
        self.on_send_message_btn_pressed()

    def on_clear_message_btn_pressed(self) -> None:
        """Clear the warnings / errors"""

        self.messages.clear() # Clear the message window
        self.messages.moveCursor(QTextCursor.End)
        self.messages.ensureCursorVisible()

    def on_clear_terminal_btn_pressed(self) -> None:
        """Clear the terminal"""

        self.terminal.clear() # Clear the serial terminal window
        self.terminal.moveCursor(QTextCursor.End)
        self.terminal.ensureCursorVisible()

    def chksum_nmea(self, sentence):
        """Calculate the NMEA checksum"""
        # Initializing our first XOR value
        csum = 0 
        # For each char in chksumdata, XOR against the previous XOR'd char.
        # The final XOR of the last char will be our  checksum
        for c in sentence:
            csum ^= ord(c)
        return csum

    def on_send_message_btn_pressed(self) -> None:
        """Send the message to the modem"""

        portAvailable = False
        for desc, name, sys in gen_serial_ports():
            try:
                if (sys == self.port):
                    portAvailable = True
            except:
                pass

        if (portAvailable == False):
            self.messages.moveCursor(QTextCursor.End)
            self.messages.ensureCursorVisible()
            self.messages.appendPlainText("Error: Port No Longer Available!")
            self.messages.ensureCursorVisible()
            try:
                self.ser.close()
            except:
                pass
            self.endTimer()
            return
        
        try:
            if self.ser.isOpen():
                portAvailable = True
            else:
                portAvailable = False
        except:
            portAvailable = False

        if (portAvailable == False):
            self.messages.moveCursor(QTextCursor.End)
            self.messages.ensureCursorVisible()
            self.messages.appendPlainText("Error: Port Is Not Open!")
            self.messages.ensureCursorVisible()
            try:
                self.ser.close()
            except:
                pass
            self.endTimer()
            return

        if (self.config.toPlainText() == ''):
            self.messages.moveCursor(QTextCursor.End)
            self.messages.ensureCursorVisible()
            self.messages.appendPlainText("Warning: Nothing To Do! Message Is Empty!")
            self.messages.ensureCursorVisible()
            return

        self.ser.write(bytes('$','utf-8')) # Send the $
        self.ser.write(bytes(self.config.toPlainText(),'utf-8')) # Send the config message
        self.ser.write(bytes('*','utf-8')) # Send the *
        self.ser.write(str.format('{:02X}', self.chksum_nmea(self.config.toPlainText())).encode('utf-8'))
        self.ser.write(bytes('\n','utf-8'))

        msg = "$"
        msg += self.config.toPlainText()
        msg += "*"
        msg += str.format('{:02X}', self.chksum_nmea(self.config.toPlainText())).encode('utf-8').decode('utf-8')
        msg += "\n"

        self.terminal.moveCursor(QTextCursor.End)
        self.terminal.ensureCursorVisible()        
        self.terminal.appendPlainText(msg)
        self.terminal.ensureCursorVisible()

        if self.fileOpen == True:
            try:
                self.f.write(msg);
            except IOError:
                self.fileOpen = False
                self.messages.moveCursor(QTextCursor.End)
                self.messages.ensureCursorVisible()
                self.messages.appendPlainText("Error: Could Not Write To File!")
                self.messages.ensureCursorVisible()
                try:
                    self.f.close();
                except:
                    pass

    def update_com_ports(self) -> None:
        """Update COM Port list in GUI."""
        self.port_combobox.clear()
        for desc, name, sys in gen_serial_ports():
            longname = desc + " (" + name + ")"
            self.port_combobox.addItem(longname, sys)

    @property
    def port(self) -> str:
        """Return the current serial port."""
        return self.port_combobox.currentData()

    def closeEvent(self, event: QCloseEvent) -> None:
        """Handle Close event of the Widget."""
        try:
            self.save_settings()
        except:
            pass

        try:
            self.ser.close()
        except:
            pass
        
        try:
            self.f.close()
        except:
            pass

        self.endTimer()
        
        event.accept()

    def on_open_port_btn_pressed(self) -> None:
        """Check if port is available and open it"""

        portAvailable = False
        for desc, name, sys in gen_serial_ports():
            try:
                if (sys == self.port):
                    portAvailable = True
            except:
                pass

        if (portAvailable == False):
            self.messages.moveCursor(QTextCursor.End)
            self.messages.ensureCursorVisible()
            self.messages.appendPlainText("Error: Port No Longer Available!")
            self.messages.ensureCursorVisible()
            try:
                self.ser.close()
            except:
                pass
            self.endTimer()
            return

        try:
            if self.ser.isOpen():
                portAvailable = True
            else:
                portAvailable = False
        except:
            portAvailable = False

        if (portAvailable == True):
            self.messages.moveCursor(QTextCursor.End)
            self.messages.ensureCursorVisible()
            self.messages.appendPlainText("Port Is Already Open!")
            self.messages.ensureCursorVisible()
            return
        
        try:
            self.ser = QSerialPort()
            self.ser.setPortName(self.port)
            self.ser.setBaudRate(QSerialPort.Baud115200)
            self.ser.open(QIODevice.ReadWrite)
        except:
            self.messages.moveCursor(QTextCursor.End)
            self.messages.ensureCursorVisible()
            self.messages.appendPlainText("Error: Could Not Open The Port!")
            self.messages.ensureCursorVisible()
            try:
                self.ser.close()
            except:
                pass
            self.endTimer()
            return

        self.startTimer()

        self.ser.readyRead.connect(self.receive) # Connect the receiver
        
        self.messages.clear() # Clear the message window
        self.terminal.clear() # Clear the serial terminal window
        
        self.messages.moveCursor(QTextCursor.End)
        self.messages.ensureCursorVisible()
        self.messages.appendPlainText("Port is now open")
        self.messages.ensureCursorVisible()

    @pyqtSlot()
    def receive(self) -> None:
        try:
            while self.ser.canReadLine():
                text = self.ser.readLine().data().decode()
                self.terminal.moveCursor(QTextCursor.End)
                self.terminal.ensureCursorVisible()
                self.terminal.insertPlainText(text)
                self.terminal.ensureCursorVisible()

                if self.fileOpen == True:
                    try:
                        self.f.write(text);
                    except IOError:
                        self.fileOpen = False
                        self.messages.moveCursor(QTextCursor.End)
                        self.messages.ensureCursorVisible()
                        self.messages.appendPlainText("Error: Could Not Write To File!")
                        self.messages.ensureCursorVisible()
                        try:
                            self.f.close();
                        except:
                            pass
        except:
            pass

    def startTimer(self) -> None:
        self.timer.start(1000)

    def endTimer(self) -> None:
        self.timer.stop()

    def check_port_still_available(self) -> None:
        """Check if port is still available"""

        portAvailable = False
        for desc, name, sys in gen_serial_ports():
            try:
                if (sys == self.port):
                    portAvailable = True
            except:
                pass

        if (portAvailable == False):
            self.messages.moveCursor(QTextCursor.End)
            self.messages.ensureCursorVisible()
            self.messages.appendPlainText("Error: Port No Longer Available!")
            self.messages.ensureCursorVisible()
            try:
                self.ser.close()
            except:
                pass
            self.endTimer()

    def on_close_port_btn_pressed(self) -> None:
        """Close the port"""

        portAvailable = False
        for desc, name, sys in gen_serial_ports():
            try:
                if (sys == self.port):
                    portAvailable = True
            except:
                pass
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

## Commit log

2022-09-20 Adds more measures, adds shield jumper, reduces polygon isolate to .007
    * Adds new net class for RF traces between u.FL and SMA connectors to keep .01 isolate on those
    particular traces
    * Removes Sparkx silk and adds SparkFun silk
    * Adds "Revised by" text
    * Center aligns all schematic text
    [Satellite_Transceiver_Breakout__Swarm_M138.brd, Satellite_Transceiver_Breakout__Swarm_M138.sch]
2022-09-20 Smashes all power symbols so that the correct text type would appear
    [Satellite_Transceiver_Breakout__Swarm_M138.sch]
2022-09-20 Fixes small bit of text
    [Satellite_Transceiver_Breakout__Swarm_M138.sch]
2022-09-21 Increases SHLD trace every so slightly
    [Satellite_Transceiver_Breakout__Swarm_M138.brd]
2022-09-22 Modifies trace for better aesthetics
    [Satellite_Transceiver_Breakout__Swarm_M138.brd]
2022-09-22 Updates current limiting resistors for LEDs: 1k for green and 2.2K for yellow
    [Satellite_Transceiver_Breakout__Swarm_M138.brd, Satellite_Transceiver_Breakout__Swarm_M138.sch]
2022-09-22 Adds production files
    [Satellite_Transceiver_Breakout__Swarm_M138-Panel.GBL, Satellite_Transceiver_Breakout__Swarm_M138-Panel.GBO, Satellite_Transceiver_Breakout__Swarm_M138-Panel.GB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]
2022-09-22 Fixes bottom dimension measurments being off center
    * Increases board dimension lines to .008
    [Satellite_Transceiver_Breakout__Swarm_M138.brd]
2022-09-26 Adds new panel with no vertical gaps
    [Satellite_Transceiver_Breakout__Swarm_M138-Panel.brd, Satellite_Transceiver_Breakout__Swarm_M138.brd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]

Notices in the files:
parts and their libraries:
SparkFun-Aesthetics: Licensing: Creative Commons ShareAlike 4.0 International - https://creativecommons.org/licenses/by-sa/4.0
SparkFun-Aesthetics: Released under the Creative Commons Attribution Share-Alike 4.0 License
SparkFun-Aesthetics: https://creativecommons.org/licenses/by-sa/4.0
